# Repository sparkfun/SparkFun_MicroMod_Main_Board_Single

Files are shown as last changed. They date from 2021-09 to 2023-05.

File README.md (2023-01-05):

SparkFun MicroMod Main Board - Single
========================================

SparkFun MicroMod Main Board - Single (https://www.sparkfun.com/products/20748)

[*SparkFun MicroMod Main Board - Single (DEV-20748)*](https://www.sparkfun.com/products/20748)

The MicroMod Main Board - Single is a specialized carrier board that allows you to interface a MicroMod Processor Board with a single MicroMod Function Board. With the M.2 MicroMod connector, connecting your Processor and Function Boards is a breeze. Simply match up the key on your board's beveled edge connector to the key on the M.2 connector and secure the boards with screws.

The Single Main Board includes one USB-C connector for power and programming the Processor Board. A jumper is available on the back of the board to isolate the USB C's shield pin. Two buttons for reset and boot are also populated on the board. Processor Board pins are also broken out as 2x5 SWD pins. Also, included on the board is a 2A resettable fuse and 3.3V/1A voltage regulator. A second 3.3V/500mA voltage regulator is included on the board to power your Qwiic-enabled devices. We've even added convenient PTH jumpers for advanced users looking to bypass the fuse and measure the current consumption on the 5V and 3.3V lines for low-power testing. For those that need to go remote with their application, the board includes a 2-pin JST connector and a single-cell LiPo MCP73831 charge IC (set to a charge rate of 500mA).

Four status LEDs are available for power and charging. These can also be disabled through jumpers. There is a microSD card socket so you can also plug in a microSD card for data logging. The microSD socket can be disabled through the I/O pins. Finally, two Qwiic connectors are populated on the board with built-in pull-up resistors to easily add Qwiic-enabled I<sup>2</sup>C devices to your projects!

Repository Contents
-------------------

* **/Firmware** - Arduino example code from the tutorial
* **/Hardware** - Eagle design files (.brd, .sch)
* **/Production** - Production panel files (.brd)

Documentation
--------------

* **[Hookup Guide V2](https://learn.sparkfun.com/tutorials/2683)** - Basic hookup guide

Product Versions
----------------
* [DEV-20748](https://www.sparkfun.com/products/20748) - v2.1
* [DEV-18632](https://www.sparkfun.com/products/18575)- Initial release, v1.1

Version History
---------------
* v2.1
* v1.1 - Initial Release

License Information
-------------------

This product is _**open source**_! 

Please review the LICENSE.md file for license information. 

If you have any questions or concerns on licensing, please contact technical support on our [SparkFun forums](https://forum.sparkfun.com/viewforum.php?f=152).

Distributed as-is; no warranty is given.

- Your friends at SparkFun.

_<COLLABORATION CREDIT>_

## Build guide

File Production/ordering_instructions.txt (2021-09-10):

panel size, 187x173mm
PCB thickness, 1.6mm
number of layers, 2
soldermask color, Red
silkscreen color, White
oz copper, 1oz
finish, HASL lead free
stencils, top
pcs per panel, 4
min trace width, 0.1778mm / 0.0070in
min drill size, 0.3048mm / 0.0120in

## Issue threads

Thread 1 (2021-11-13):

Hardware revision request: Improved power efficiency

adamgarbo, 2021-11-13:
Hi @edspark,

I'm a big fan of MicroMod products and use them extensively in my [research](https://github.com/adamgarbo/Cryologger_Glacier_Velocity_Measurement_System).

Unfortunately, one of the major drawbacks with many of the MicroMod products has been poor power efficiency (e.g., https://github.com/sparkfun/MicroMod_Data_Logging_Carrier/issues/3, https://github.com/sparkfun/MicroMod_Artemis_Processor/issues/5)

The new Main Board are exciting products. However, it would have really been nice if some of the design improvements identified in previous MicroMod products were addressed in these new designs. For example: adding a jumper pad added to the voltage divider (i.e., https://github.com/sparkfun/MicroMod_Data_Logging_Carrier/issues/1), or adding a P-MOSFET or extra regulator to control power to the microSD card.

Low-power data logging is an extremely desirable feature for end-users. While I don't anticipate a hardware revision of the Main Boards, my hope is that low-power operation can be given more consideration in future MicroMod designs.

Cheers,
Adam

edspark, 2021-11-15:
These are both excellent suggestions. I've added them to my notes for future revisions, thank you @adamgarbo.

Closed 2021-11-15.

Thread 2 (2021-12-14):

breakout 3.3V_EN

pacogomez, 2021-12-14:
Hi @edspark,
I would like to control the voltage regulator with an on/off switch and controller circuit, which will be connected to the pin on the processor (3.3V_EN). My suggestion is:
- add a breakout pin for EN signal (voltage regulator enable pin)
- add a breakout pin for 3.3V_EN (processor board pin)
In other words, convert the "Voltage Regulator Enable/VE" jumper to a two pin breakout.
Thanks.

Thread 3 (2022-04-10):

MicroMod MainBoard Double which causes the processor board to become unresponsive

paulvha, 2022-04-10:
There is a concerning issue with the MicroMod MainBoard Double which causes the processor board to become unresponsive.
It has already **killed my Micromod SAMD51 and Micromod rnf52840.** I am not alone in looking at post https://forum.sparkfun.com/viewtopic.php?f=181&t=57369. Similar problem.

Both these processor boards have been working without a problem. I had them installed in MM Data logger board AND on the MM Mainboard Double, but without the function board! I have done a number of different projects over the past weeks, and uploaded many sketches, no problems!

All I had done is :
No battery attached.
Add a function board (mine was the ESP32 WIFI) in SLOT zero.
No function board is SLOT ONE
I had changed the default power jumper setting from right (default) to left.
Upload a sketch

and **the processor board could not be reached anymore**. Similar to what happened with the other person on the post.

On my Ubuntu I do not get /dev/ttyUSB0 and /dev/ttyACM0 anymore and I have tried every trick I can think off, but nothing helps to recover:

- Remove the function board and re-power. Both the power LEDs come on, but **all MM nRF52840 does is the blue onboard led 4 x slow blink, 4 x fast blink.**
- press reset
- press and hold reset during power-on.
- press boot
- press and hold boot during power-on.
- press boot and Reset
- press and hold boot and reset during power-on.
- Used the MM data logger board instead of mainboard
- Used the MM  ATP (DEV-16885)
- Reboot the Ubuntu system
- Connect to a windows system USB

Nothing.. processor boards are dead as they can be, only the nRF52840 led blinking 4x slow, 4 x fast.

I suspected impact from the Power Jumper setting option.

On the ESP32 WIFI function board, the PWR-enablement pin is pulled HIGH with resistor R12 near the LDO. So the power is always ON, unless it is switched OFF in a sketch. The PWR-EN0 is HIGH from the moment the power is applied.

On the MM MainBoard double, the PWR_EN0 is connected to MM processor board connector SDIO-data2 (68).

With the power Jumper setting to the left, the PWR_EN0 is now also connected to G5-Jumper on the MM-processor board, which is now HIGH as well. (coming from PWR_EN0)

On the MM nRF52840 processor board, the SDIO-data2 is not only connected to the nRF52840 BUT ALSO connected to the on-board flash.
When now uploading a sketch... what does that 'HIGH' impact when trying to load the flash memory?

BUT....

On the MM SAMD51 processor board, the SDIO-data2 is not used and while G5-jumper is HIGH, it is just a normal GPIO. But I can't think of a reason why that would damage the board. The same applies to the MM STM32 that was used by the other person.

Other thoughts :

- One could think it is because the USB and CAN connections are also going to function zero connector, but the ESP32 Wifi function board does not use these.

- If it is not the power jumper, might it be that too much current is taken by both the processor board and function board during flashing the sketch?

- I am not sure whether I had the MicroSD still in the reader for the MM mainboard double together with the function board. I had been using it before (and left it in during uploading an updated sketch without problems. Maybe that took extra power ??

I still have an MM Artemis and MM ESP32.. but killing 2 boards is enough. I can and make errors, but given that another user (mentioned in the earlier link) had the same issue, given that it is SOO easy to happen.. I **think Sparkfun should look at this.**

regards,
Paul

p.s.
Brave, or stupid, as I am. I removed the function board, installed the MM Artemis on the MM mainboard double, and uploaded the example sketch from the hookup guide. Powered down, added the ESP32 WIFI function board, powered up and it worked. But to be sure.. **I will not upload a sketch with the function board inserted...**

paulvha, 2022-04-14:
I have updated with an observation about the charge led on the Sparkfun Forum.
regards,
Paul

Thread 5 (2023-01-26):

CAN-RX and CAN-TX Labels are reversed on MICROMOD_FUNCTION symbol

NPoole, 2023-01-26:
As it's currently labeled, this board appears to connect the processor board's CAN-RX to the function board's CAN-TX and vise versa, but this is incorrect. I've updated the library symbol in the Eagle library to fix the labels without changing the wiring. Next time this board gets revved, replace MICROMOD_FUNCTION_MAIN with the new version and replace pins "by coordinates" (not "by names") in order to ensure the schematic is fixed.

To reiterate, the correct connection scheme is TX-TX and RX-RX

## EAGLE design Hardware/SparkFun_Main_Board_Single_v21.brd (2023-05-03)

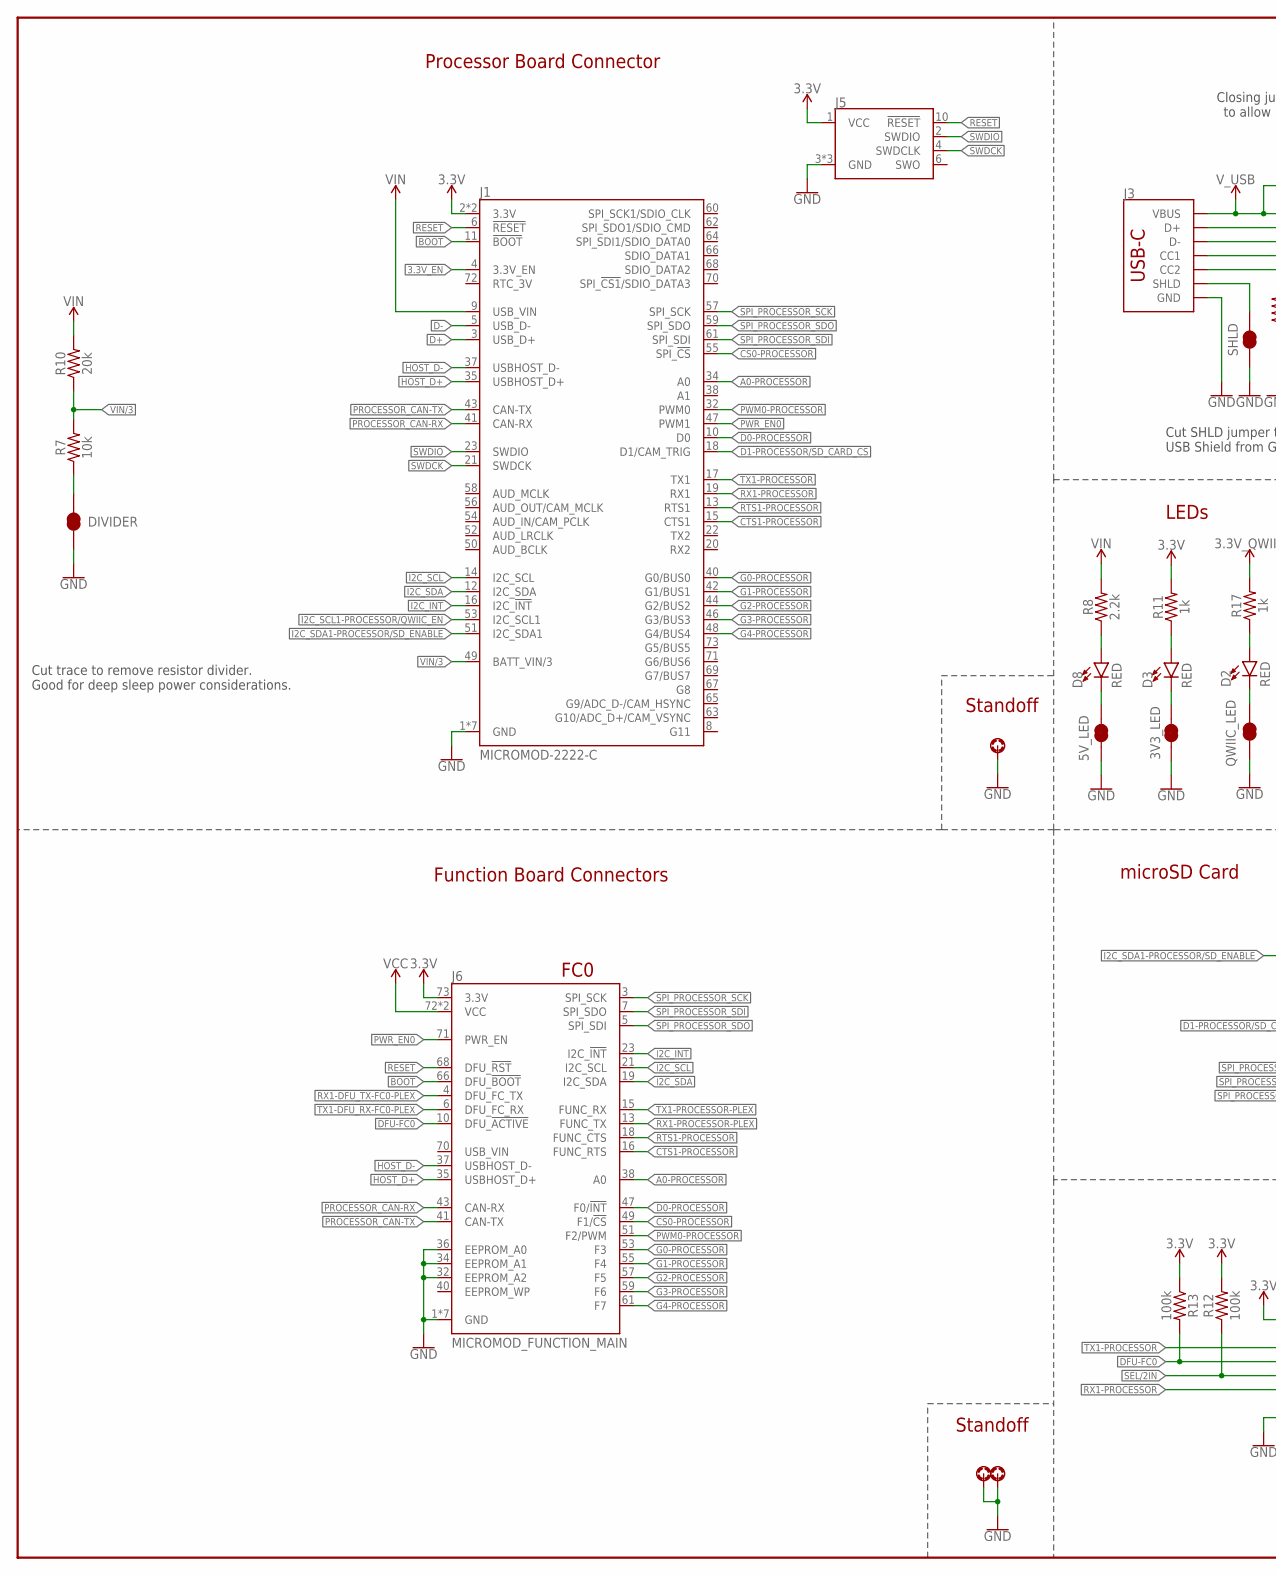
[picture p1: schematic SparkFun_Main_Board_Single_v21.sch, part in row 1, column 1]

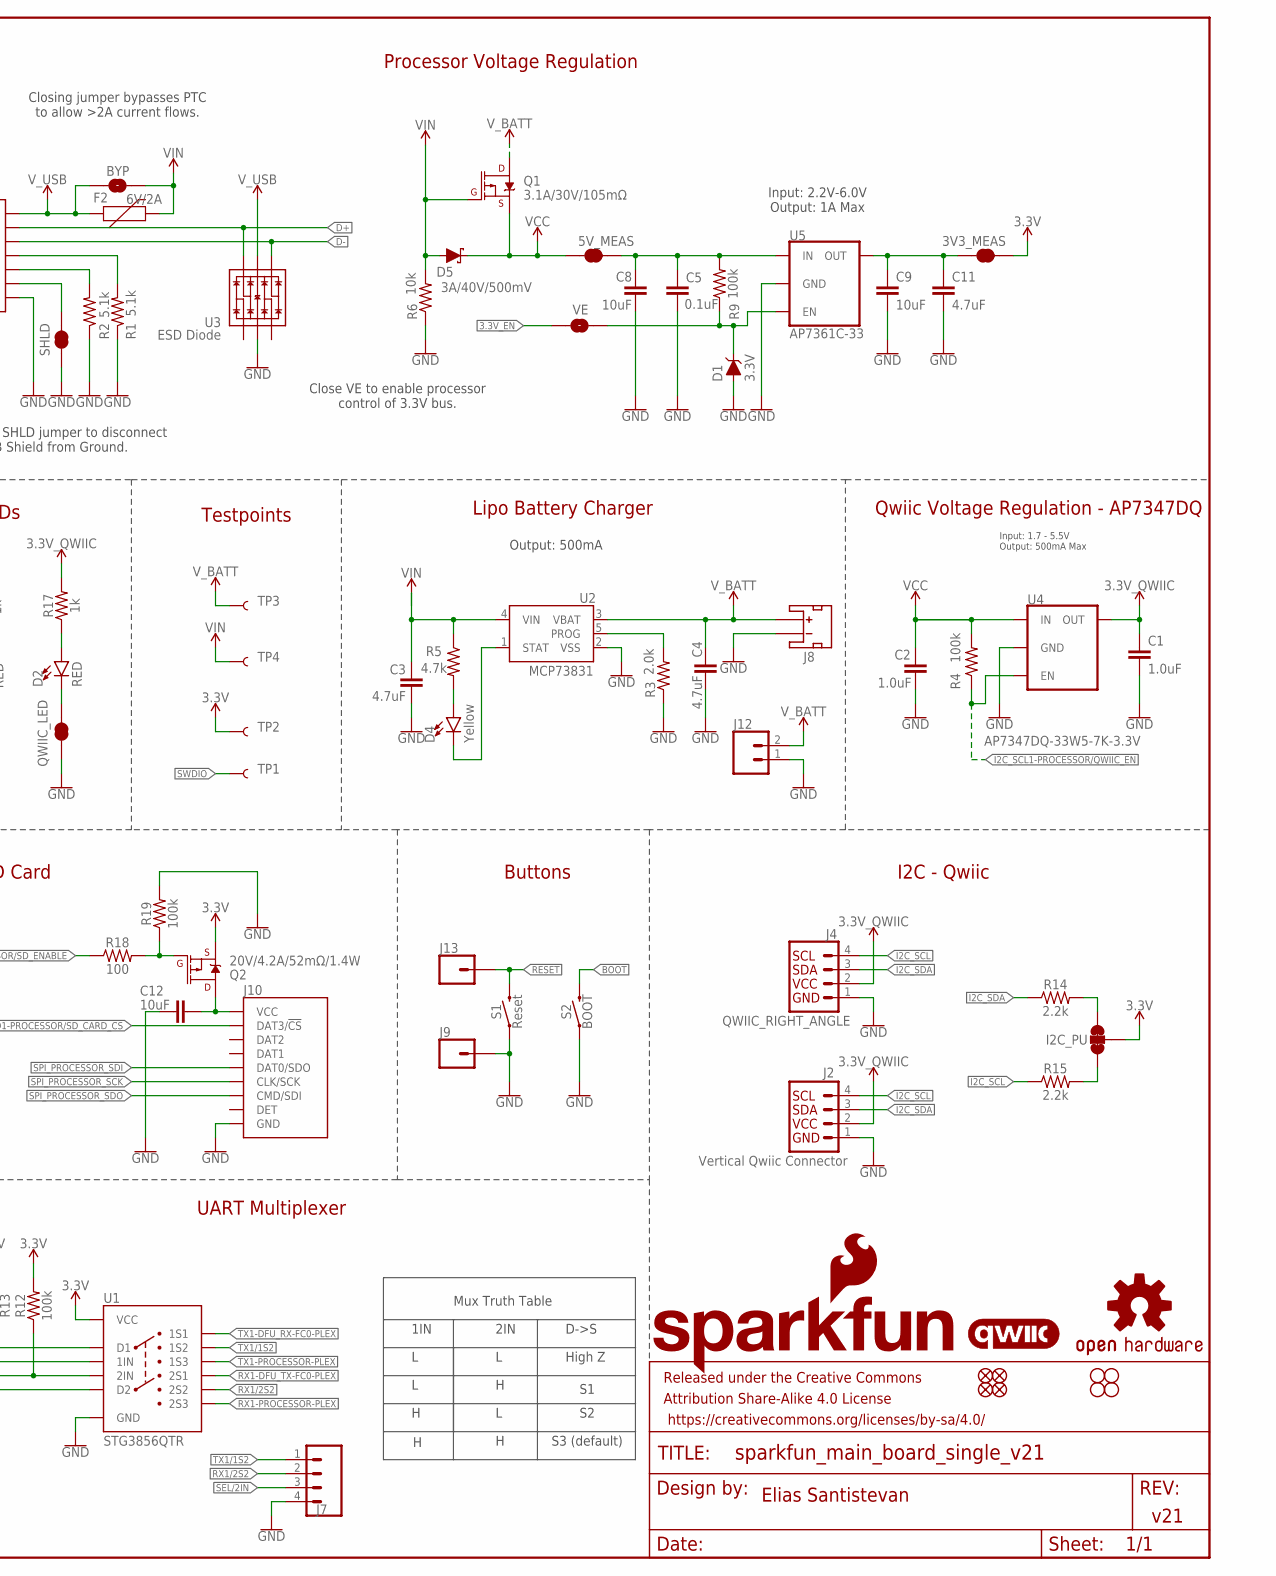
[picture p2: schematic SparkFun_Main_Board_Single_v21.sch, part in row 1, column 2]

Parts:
3V3_LED, 5V_LED: JUMPER-SMT_2_NC_TRACE_SILK; SMT-JUMPER_2_NC_TRACE_SILK
3V3_MEAS, 5V_MEAS: JUMPER-COMBO_2_NC_TRACE; COMBO-JUMPER_2_NC_TRACE
BYP: JUMPER-SMT_2_NO_SILK; SMT-JUMPER_2_NO_SILK
C1, C2: 1.0uF; 0603
C3, C4, C11: 4.7uF; 0603
C5: 0.1uF; 0603
C8: 10uF; 0805
C9, C12: 10uF; 0603
D1: 3.3V; SOD-323
D2, D3, D8: RED; LED-0603
D4: Yellow; LED-0603
D5: 3A/40V/500mV; SMA-DIODE
DIVIDER: JUMPER-SMT_2_NC_TRACE_SILK; SMT-JUMPER_2_NC_TRACE_SILK
F2: 6V/2A; 1210
FD1, FD2, FD3, FD4: FIDUCIAL1X2; FIDUCIAL-1X2
FRAME1: FRAME-LEDGER; CREATIVE_COMMONS
H2, H4, H8: STAND-OFF-REFLOW-M2.5_2.5MM_TALL; STAND-OFF-REFLOW-M2.5
H14, H15, H16, H17: STAND-OFFTIGHT; STAND-OFF-TIGHT
I2C_PU: JUMPER-SMT_3_2-NC_TRACE_SILK; SMT-JUMPER_3_2-NC_TRACE_SILK
J1: MICROMOD-2222-C; M.2-CONNECTOR-E
J2: Vertical Qwiic Connector; JST04_1MM_VERT
J3: USB_C_2-LAYER_PADS; USB-C-16P-2LAYER-PADS
J4: QWIIC_RIGHT_ANGLE; JST04_1MM_RA
J5: CORTEX_JTAG_DEBUG_MINIMUM_PTH; 2X5-PTH-1.27MM
J6: MICROMOD_FUNCTION_MAIN; M.2-CONNECTOR-E-FUNCTION-STANDARD
J7: CONN_041X04_NO_SILK; 1X04_NO_SILK
J8: JST_2MM_MALE; JST-2-SMD
J9, J13: CONN_01PTH_NO_SILK_YES_STOP; 1X01_NO_SILK
J10: MICRO-SD-PUSH-PUSH-EXT-PIN; MICROSD-EXTERNALPIN
J12: CONN_021X02_NO_SILK; 1X02_NO_SILK
LOGO1: QWIIC_LOGO_8MM; QWIIC_8MM
LOGO2: SFE_LOGO_NAME_FLAME.3_INCH; SFE_LOGO_NAME_FLAME_.3
LOGO3: OSHW-LOGOL; OSHW-LOGO-L
Q1: 3.1A/30V/105mΩ; SOT23-3
Q2: 20V/4.2A/52mΩ/1.4W; SOT23-3
QWIIC_LED: JUMPER-SMT_2_NC_TRACE_SILK; SMT-JUMPER_2_NC_TRACE_SILK
R1, R2: 5.1k; 0603
R3: 2.0k; 0603
R4, R9, R12, R13, R19: 100k; 0603
R5: 4.7k; 0603
R6, R7: 10k; 0603
R8, R14, R15: 2.2k; 0603
R10: 20k; 0603
R11, R17: 1k; 0603
R18: 100; 0603
S1: Reset; TACTILE_SWITCH_SMD_5.2MM
S2: BOOT; TACTILE_SWITCH_SMD_5.2MM
SHLD: JUMPER-SMT_2_NC_TRACE_SILK; SMT-JUMPER_2_NC_TRACE_SILK
TP1, TP2, TP3, TP4: TEST-POINT3X5; PAD.03X.05
U1: STG3856QTR; STG3856
U2: MCP73831; SOT23-5
U3: ESD Diode; SOT-23-6
U4: AP7347DQ-33W5-7K-3.3V; SOT25
U5: AP7361C-33; UDFN-8
VE: JUMPER-SMT_2_NO_SILK; SMT-JUMPER_2_NO_SILK

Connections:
3.3V: 3V3_MEAS.2, 3V3_MEAS.4 (2), I2C_PU.2, J1.2 (3.3V), J1.74 (3.3V), J5.1 (VCC), J6.73 (3.3V), Q2.2 (S), R11.2, R12.2, R13.1, TP2.1, U1.P11 (VCC)
3.3V_EN: J1.4 (3.3V_EN), VE.1
3.3V_EN_VE: D1.C, R9.1, U5.5 (EN), VE.2
3.3V_QWIIC: C1.1, J2.2, J4.2, R17.2, U4.5 (OUT)
3V3_MEAS: 3V3_MEAS.1, 3V3_MEAS.3 (1), C9.1, C11.1, U5.1 (OUT)
!BOOT!: J1.11 (!BOOT!), J6.66 (DFU_!BOOT!), S2.3 (2), S2.4 (2)
!CS0!-PROCESSOR: J1.55 (SPI_!CS!), J6.49 (F1/!CS!)
!DFU-FC0!: J6.10 (DFU_!ACTIVE!), R13.2, U1.P12 (1IN)
!RESET!: J1.6 (!RESET!), J5.10 (!RESET), J6.68 (DFU_!RST!), J13.1, S1.3 (2), S1.4 (2)
!SEL!/2IN: J7.3, R12.1, U1.P10 (2IN)
A0-PROCESSOR: J1.34 (A0), J6.38 (A0)
CTS1-PROCESSOR: J1.15 (CTS1), J6.16 (FUNC_RTS)
D0-PROCESSOR: J1.10 (D0), J6.47 (F0/!INT!)
D1-PROCESSOR/SD_CARD_!CS!: J1.18 (D1/CAM_TRIG), J10.2 (DAT3/!CS!)
D+: J1.3 (USB_D+), J3.A6 (D+), J3.B6 (D+), U3.6 (IO4)
D-: J1.5 (USB_D-), J3.A7 (D-), J3.B7 (D-), U3.4 (IO3)
G0-PROCESSOR: J1.40 (G0/BUS0), J6.53 (F3)
G1-PROCESSOR: J1.42 (G1/BUS1), J6.55 (F4)
G2-PROCESSOR: J1.44 (G2/BUS2), J6.57 (F5)
G3-PROCESSOR: J1.46 (G3/BUS3), J6.59 (F6)
G4-PROCESSOR: J1.48 (G4/BUS4), J6.61 (F7)
GND: 3V3_LED.1, 5V_LED.1, C1.2, C2.2, C3.2, C4.2, C5.2, C8.2, C9.2, C11.2, C12.2, D1.A, DIVIDER.1, H2.1, H4.1, H8.1, J1.1 (GND), J1.7 (GND), J1.33 (GND), J1.36 (GND), J1.39 (GND), J1.45 (GND), J1.75 (GND), J2.1, J3.GND, J3.GND2 (GND), J4.1, J5.3 (GND), J5.5 (GND), J5.9 (GND), J6.1 (GND), J6.2 (GND), J6.8 (GND), J6.32 (EEPROM_A2), J6.33 (GND), J6.34 (EEPROM_A1), J6.36 (EEPROM_A0), J6.39 (GND), J6.45 (GND), J6.75 (GND), J7.4, J8.1 (-), J9.1, J10.6 (GND), J10.10 (GND), J10.11 (GND), J10.12 (GND), J10.13 (GND), J12.1, QWIIC_LED.1, R1.1, R2.1, R3.1, R6.1, R19.2, S1.1, S1.2 (1), S2.1, S2.2 (1), SHLD.1, U1.P5 (GND), U2.2 (VSS), U3.2 (VSS), U4.2 (GND), U5.4 (GND), U5.EP (GND)
HOST_D+: J1.35 (USBHOST_D+), J6.35 (USBHOST_D+)
HOST_D-: J1.37 (USBHOST_D-), J6.37 (USBHOST_D-)
I2C_!INT!: J1.16 (I2C_!INT!), J6.23 (I2C_!INT!)
I2C_SCL: J1.14 (I2C_SCL), J2.4, J4.4, J6.21 (I2C_SCL), R15.1
I2C_SCL1-PROCESSOR/QWIIC_EN: J1.53 (I2C_SCL1), R4.1, U4.3 (EN)
I2C_SDA: J1.12 (I2C_SDA), J2.3, J4.3, J6.19 (I2C_SDA), R14.1
I2C_SDA1-PROCESSOR/!SD_ENABLE!: J1.51 (I2C_SDA1), R18.1
unnamed: 5V_LED.2, D8.C
unnamed: D3.A, R11.1
unnamed: J3.B5 (CC2), R2.2
unnamed: J3.A5 (CC1), R1.2
unnamed: R3.2, U2.5 (PROG)
unnamed: DIVIDER.2, R7.1
unnamed: D4.C, U2.1 (STAT)
unnamed: D4.A, R5.2
unnamed: 3V3_LED.2, D3.C
unnamed: I2C_PU.3, R14.2
unnamed: D8.A, R8.1
unnamed: I2C_PU.1, R15.2
unnamed: D2.A, R17.1
unnamed: D2.C, QWIIC_LED.2
unnamed: C12.1, J10.4 (VCC), Q2.3 (D)
unnamed: Q2.1 (G), R18.2, R19.1
PROCESSOR_CAN-RX: J1.41 (CAN-RX), J6.43 (CAN-RX)
PROCESSOR_CAN-TX: J1.43 (CAN-TX), J6.41 (CAN-TX)
PWM0-PROCESSOR: J1.32 (PWM0), J6.51 (F2/PWM)
PWR_EN0: J1.47 (PWM1), J6.71 (PWR_EN)
RTS1-PROCESSOR: J1.13 (RTS1), J6.18 (FUNC_CTS)
RX1-DFU_TX-FC0-PLEX: J6.4 (DFU_FC_TX), U1.P9 (2S1)
RX1-PROCESSOR: J1.19 (RX1), U1.P6 (D2)
RX1-PROCESSOR-PLEX: J6.13 (FUNC_TX), U1.P7 (2S3)
RX1/2S2: J7.2, U1.P8 (2S2)
SHLD: J3.SHLD1 (SHLD), J3.SHLD2 (SHLD), J3.SHLD3 (SHLD), J3.SHLD4 (SHLD), SHLD.2
SPI_PROCESSOR_SCK: J1.57 (SPI_SCK), J6.3 (SPI_SCK), J10.5 (CLK/SCK)
SPI_PROCESSOR_SDI: J1.61 (SPI_SDI), J6.7 (SPI_SDO), J10.7 (DAT0/SDO)
SPI_PROCESSOR_SDO: J1.59 (SPI_SDO), J6.5 (SPI_SDI), J10.3 (CMD/SDI)
SWDCK: J1.21 (SWDCK), J5.4 (SWDCLK)
SWDIO: J1.23 (SWDIO), J5.2 (SWDIO), TP1.1
TX1-DFU_RX-FC0-PLEX: J6.6 (DFU_FC_RX), U1.P1 (1S1)
TX1-PROCESSOR: J1.17 (TX1), U1.P4 (D1)
TX1-PROCESSOR-PLEX: J6.15 (FUNC_RX), U1.P3 (1S3)
TX1/1S2: J7.1, U1.P2 (1S2)
VCC: 5V_MEAS.1, 5V_MEAS.3 (1), C2.1, D5.C, J6.72 (VCC), J6.74 (VCC), Q1.2 (S), R4.2, U4.1 (IN)
VCC_MEAS: 5V_MEAS.2, 5V_MEAS.4 (2), C5.1, C8.1, R9.2, U5.8 (IN)
VIN: BYP.2, C3.1, D5.A, F2.2, J1.9 (USB_VIN), Q1.1 (G), R5.1, R6.2, R8.2, R10.2, TP4.1, U2.4 (VIN)
VIN/3: J1.49 (BATT_VIN/3), R7.2, R10.1
V_BATT: C4.1, J8.2 (+), J12.2, Q1.3 (D), TP3.1, U2.3 (VBAT)
V_USB: BYP.1, F2.1, J3.VBUS1 (VBUS), J3.VBUS2 (VBUS), U3.5 (VCC)

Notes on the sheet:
Function Board Connectors
Processor Board Connector
v21
I2C - Qwiic
FC0
Lipo Battery Charger
Testpoints
Processor Voltage Regulation
Closing jumper bypasses PTC to allow >2A current flows.
Input: 2.2V-6.0V Output: 1A Max
Close VE to enable processor control of 3.3V bus.
LEDs
Buttons
Elias Santistevan
Standoff
Mux Truth Table
1IN
2IN
D->S
High Z
S3 (default)
UART Multiplexer
Qwiic Voltage Regulation - AP7347DQ
Input: 1.7 - 5.5V Output: 500mA Max
Output: 500mA
Cut SHLD jumper to disconnect USB Shield from Ground.
microSD Card
Cut trace to remove resistor divider. Good for deep sleep power considerations.

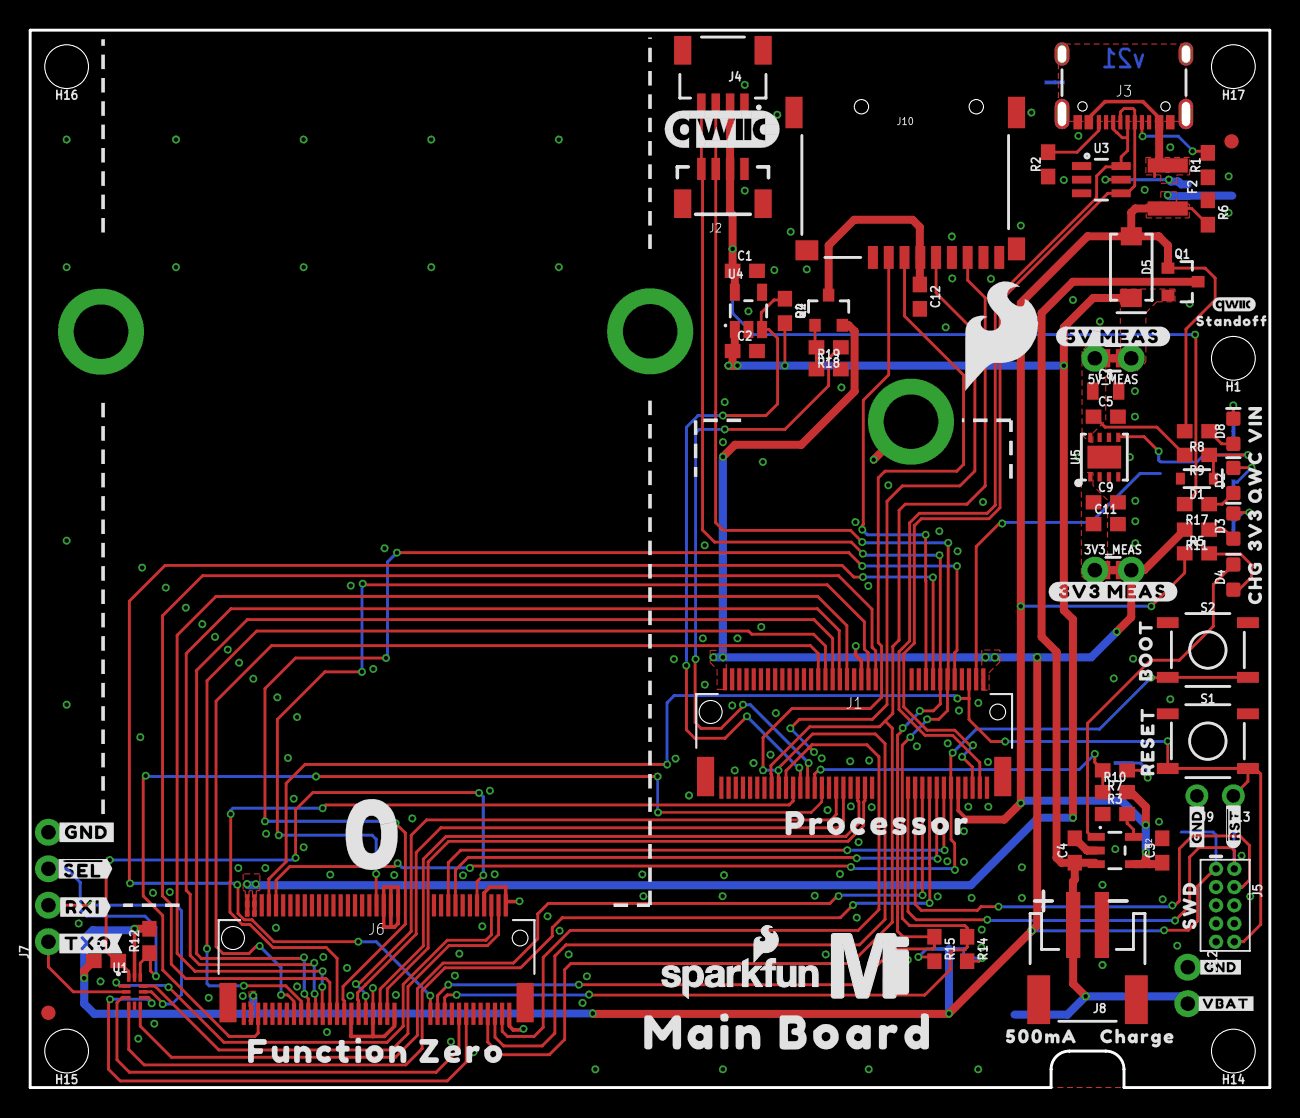
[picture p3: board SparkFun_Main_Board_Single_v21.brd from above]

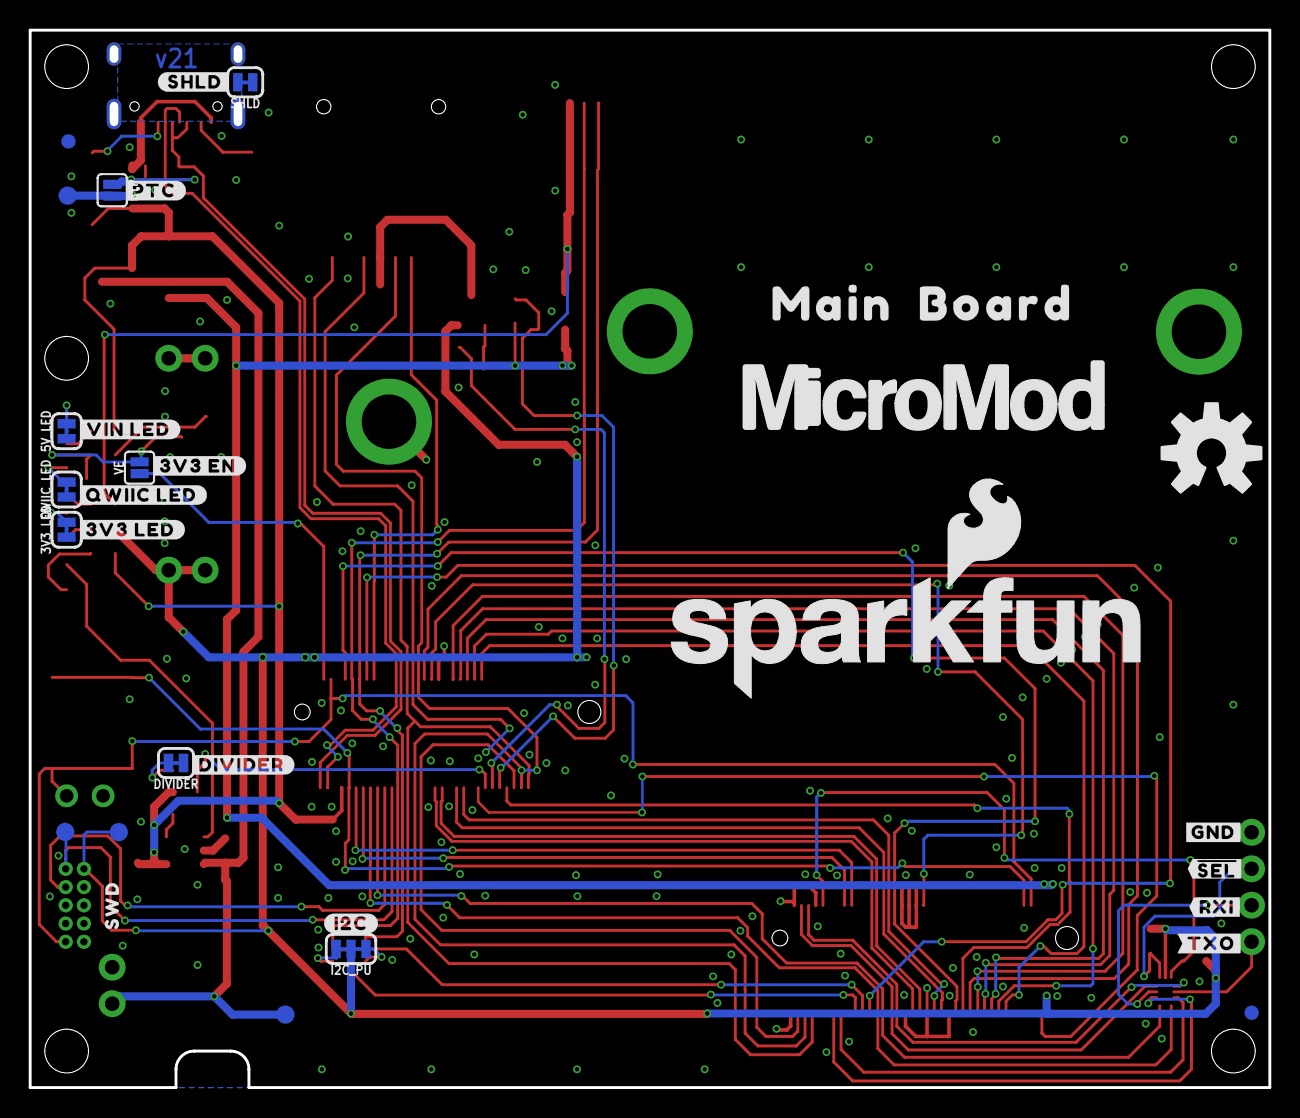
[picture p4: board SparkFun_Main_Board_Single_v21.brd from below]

Board: 2 copper layers, 86.4 x 73.7 mm, 130 parts (32 on the bottom side), 70 nets.

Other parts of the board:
FRAME2: FRAME-LEDGERNO_FOOTPRINT; DUMMY
H1: STAND-OFFTIGHT; STAND-OFF-TIGHT
U$1: #TXO#7
U$2: #RXI#6
U$3: #PTC#15
U$4: 3V332533
U$5: VIN32532
U$6: CHG32531
U$7: #SHLD#501
U$8: BOOT32541
U$9: RESET32540
U$10: PROCESSOR525
U$11: FUNCTION_ZERO520
U$12: ##SEL##5
U$13: MAIN523
U$14: MICROMOD_MI_LOGO_1
U$15: 0523
U$16, U$29: #GND#3
U$17: MICROMOD_LOGO_1
U$18: BOARD524
U$19: ##SEL##3
U$20: #RXI#4
U$21: MAIN_BOARD5523
U$22: QWIIC_3MM
U$23: STANDOFF501
U$24: SFE_LOGO_FLAME_.3
U$25, U$32: SWD6522
U$26: #3V3_MEAS#6522
U$27: CHARGE501
U$28: #TXO#5
U$30: #I2C#501
U$31: #5V_MEAS#6522
U$33: 500MA6520
U$34: SFE_LOGO_NAME_FLAME_.1
U$35: QWC4
U$36, U$37: #GND#10
U$38: ##RST##8
U$39: #VBAT#9
U$49: #3V3_EN#23
U$50: #3V3_LED#22
U$51: #QWIIC_LED#22
U$52: #DIVIDER#23
U$53: #VIN_LED#24

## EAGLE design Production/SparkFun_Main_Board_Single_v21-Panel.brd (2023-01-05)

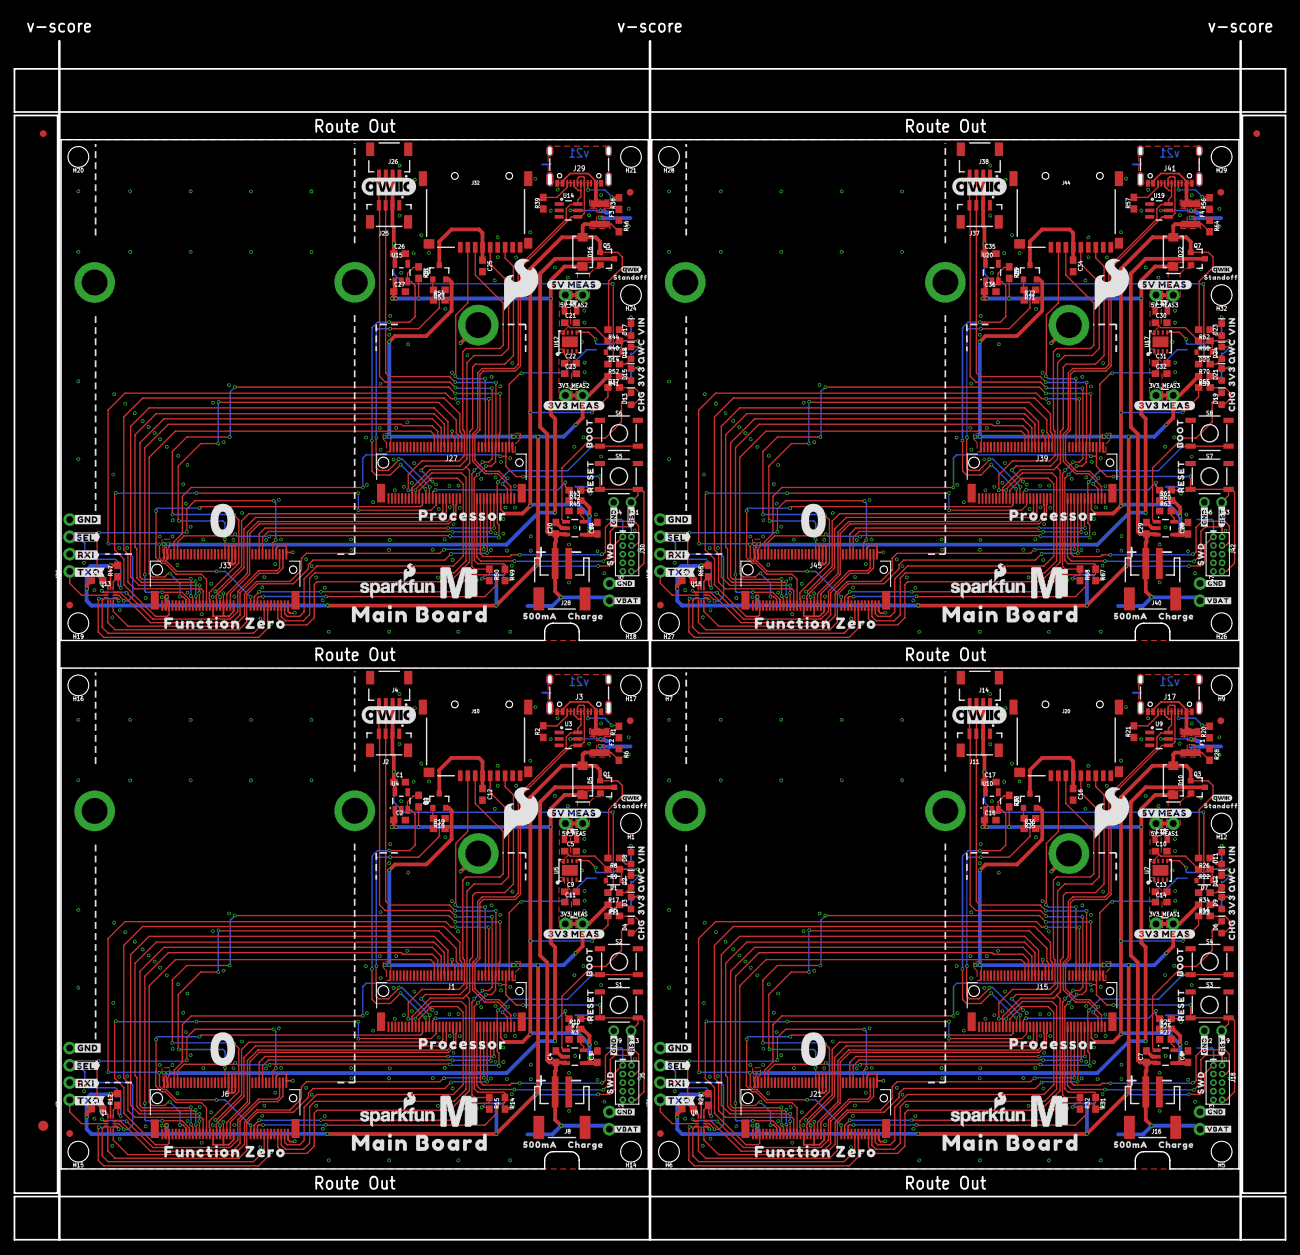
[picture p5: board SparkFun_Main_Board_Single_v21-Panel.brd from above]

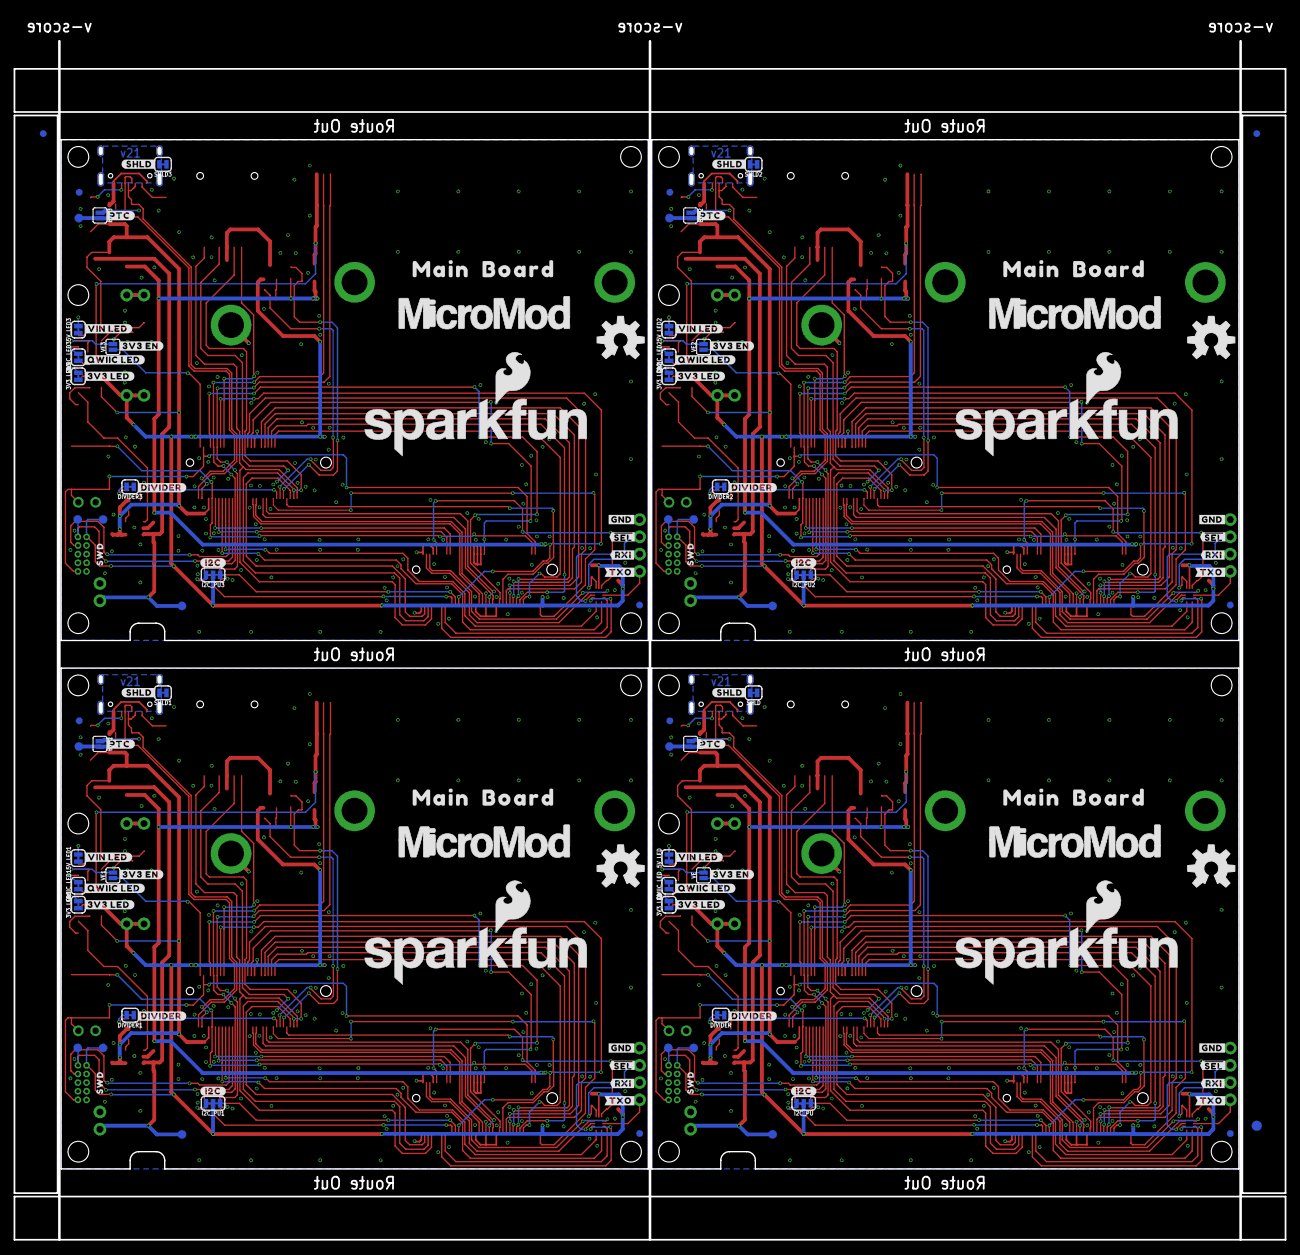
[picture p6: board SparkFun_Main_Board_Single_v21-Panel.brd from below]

Board: 2 copper layers, 186.9 x 176.3 mm, 518 parts (131 on the bottom side), 280 nets.

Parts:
3V3_LED, 3V3_LED1, 3V3_LED2, 3V3_LED3, 5V_LED, 5V_LED1, 5V_LED2, 5V_LED3: JUMPER-SMT_2_NC_TRACE_SILK; SMT-JUMPER_2_NC_TRACE_SILK
3V3_MEAS, 3V3_MEAS1, 3V3_MEAS2, 3V3_MEAS3, 5V_MEAS, 5V_MEAS1, 5V_MEAS2, 5V_MEAS3: JUMPER-COMBO_2_NC_TRACE; COMBO-JUMPER_2_NC_TRACE
BYP, BYP1, BYP2, BYP3: JUMPER-SMT_2_NO_SILK; SMT-JUMPER_2_NO_SILK
C1, C2, C17, C18, C26, C27, C35, C36: 1.0uF; 0603
C3, C4, C6, C7, C11, C14, C19, C20, C23, C28, C29, C32: 4.7uF; 0603
C5, C10, C21, C30: 0.1uF; 0603
C8, C15, C24, C33: 10uF; 0805
C9, C12, C13, C16, C22, C25, C31, C34: 10uF; 0603
D1, D7, D14, D20: 3.3V; SOD-323
D2, D3, D8, D9, D11, D12, D15, D17, D18, D21, D23, D24: RED; LED-0603
D4, D6, D13, D19: Yellow; LED-0603
D5, D10, D16, D22: 3A/40V/500mV; SMA-DIODE
DIVIDER, DIVIDER1, DIVIDER2, DIVIDER3: JUMPER-SMT_2_NC_TRACE_SILK; SMT-JUMPER_2_NC_TRACE_SILK
E$1, E$2, E$3, E$4: FIDUCIAL-1X2
E$5, E$6: FIDUCIAL-1.5X3
F1, F2, F3, F4: 6V/2A; 1210
FD1, FD2, FD3, FD4, FD5, FD6, FD7, FD8, FD9, FD10, FD11, FD12, FD13, FD14, FD15, FD16: FIDUCIAL1X2; FIDUCIAL-1X2
H1, H5, H6, H7, H9, H12, H14, H15, H16, H17, H18, H19, H20, H21, H24, H26, H27, H28, H29, H32: STAND-OFFTIGHT; STAND-OFF-TIGHT
H2, H3, H4, H8, H10, H11, H13, H22, H23, H25, H30, H31: STAND-OFF-REFLOW-M2.5_2.5MM_TALL; STAND-OFF-REFLOW-M2.5
I2C_PU, I2C_PU1, I2C_PU2, I2C_PU3: JUMPER-SMT_3_2-NC_TRACE_SILK; SMT-JUMPER_3_2-NC_TRACE_SILK
J1, J15, J27, J39: MICROMOD-2222-C; M.2-CONNECTOR-E
J2, J11, J25, J37: Vertical Qwiic Connector; JST04_1MM_VERT
J3, J17, J29, J41: USB-C-16P-2LAYER-PADS
J4, J14, J26, J38: QWIIC_RIGHT_ANGLE; JST04_1MM_RA
J5, J18, J30, J42: CORTEX_JTAG_DEBUG_MINIMUM_PTH; 2X5-PTH-1.27MM
J6, J21, J33, J45: MICROMOD_FUNCTION_MAIN; M.2-CONNECTOR-E-FUNCTION-STANDARD
J7, J24, J36, J48: 1X04_NO_SILK
J8, J16, J28, J40: JST-2-SMD
J9, J13, J19, J22, J31, J34, J43, J46: 1X01_NO_SILK
J10, J20, J32, J44: MICRO-SD-PUSH-PUSH-EXT-PIN; MICROSD-EXTERNALPIN
J12, J23, J35, J47: 1X02_NO_SILK
LOGO1, LOGO4, LOGO7, LOGO10: QWIIC_LOGO_8MM; QWIIC_8MM
LOGO2, LOGO5, LOGO8, LOGO11: SFE_LOGO_NAME_FLAME.3_INCH; SFE_LOGO_NAME_FLAME_.3
LOGO3, LOGO6, LOGO9, LOGO12: OSHW-LOGOL; OSHW-LOGO-L
Q1, Q3, Q5, Q7: 3.1A/30V/105mΩ; SOT23-3
Q2, Q4, Q6, Q8: 20V/4.2A/52mΩ/1.4W; SOT23-3
QWIIC_LED, QWIIC_LED1, QWIIC_LED2, QWIIC_LED3: JUMPER-SMT_2_NC_TRACE_SILK; SMT-JUMPER_2_NC_TRACE_SILK
R1, R2, R20, R21, R38, R39, R56, R57: 5.1k; 0603
R3, R27, R45, R63: 2.0k; 0603
R4, R9, R12, R13, R19, R22, R29, R30, R33, R36, R40, R47, R48, R51, R54, R58, R65, R66, R69, R72: 100k; 0603
R5, R16, R37, R55: 4.7k; 0603
R6, R7, R24, R28, R42, R46, R60, R64: 10k; 0603
R8, R14, R15, R26, R31, R32, R44, R49, R50, R62, R67, R68: 2.2k; 0603
R10, R25, R43, R61: 20k; 0603
R11, R17, R23, R34, R41, R52, R59, R70: 1k; 0603
R18, R35, R53, R71: 100; 0603
S1, S3, S5, S7: Reset; TACTILE_SWITCH_SMD_5.2MM
S2, S4, S6, S8: BOOT; TACTILE_SWITCH_SMD_5.2MM
SHLD, SHLD1, SHLD2, SHLD3: JUMPER-SMT_2_NC_TRACE_SILK; SMT-JUMPER_2_NC_TRACE_SILK
TP1, TP2, TP3, TP4, TP5, TP6, TP7, TP8, TP9, TP10, TP11, TP12, TP13, TP14, TP15, TP16: TEST-POINT3X5; PAD.03X.05
U1, U8, U13, U18: STG3856QTR; STG3856
U2, U6, U11, U16: MCP73831; SOT23-5
U3, U9, U14, U19: ESD Diode; SOT-23-6
U4, U10, U15, U20: AP7347DQ-33W5-7K-3.3V; SOT25
U5, U7, U12, U17: AP7361C-33; UDFN-8
U$1, U$78, U$122, U$166: #TXO#7
U$2, U$79, U$123, U$167: #RXI#6
U$3, U$84, U$128, U$172: #PTC#15
U$4, U$40, U$89, U$133: 3V332533
U$5, U$41, U$90, U$134: VIN32532
U$6, U$42, U$91, U$135: CHG32531
U$7, U$62, U$106, U$150: #SHLD#501
U$8, U$43, U$92, U$136: BOOT32541
U$9, U$44, U$93, U$137: RESET32540
U$10, U$45, U$94, U$138: PROCESSOR525
U$11, U$46, U$95, U$139: FUNCTION_ZERO520
U$12, U$80, U$124, U$168: ##SEL##5
U$13, U$54, U$98, U$142: MAIN523
U$14, U$47, U$96, U$140: MICROMOD_MI_LOGO_1
U$15, U$48, U$97, U$141: 0523
U$16, U$29, U$73, U$74, U$117, U$118, U$161, U$162: #GND#3
U$17, U$57, U$101, U$145: MICROMOD_LOGO_1
U$18, U$55, U$99, U$143: BOARD524
U$19, U$81, U$125, U$169: ##SEL##3
U$20, U$82, U$126, U$170: #RXI#4
U$21, U$56, U$100, U$144: MAIN_BOARD5523
U$22, U$58, U$102, U$146: QWIIC_3MM
U$23, U$59, U$103, U$147: STANDOFF501
U$24, U$60, U$104, U$148: SFE_LOGO_FLAME_.3
U$25, U$32, U$66, U$75, U$110, U$119, U$154, U$163: SWD6522
U$26, U$63, U$107, U$151: #3V3_MEAS#6522
U$27, U$61, U$105, U$149: CHARGE501
U$28, U$83, U$127, U$171: #TXO#5
U$30, U$72, U$116, U$160: #I2C#501
U$31, U$64, U$108, U$152: #5V_MEAS#6522
U$33, U$65, U$109, U$153: 500MA6520
U$34, U$76, U$120, U$164: SFE_LOGO_NAME_FLAME_.1
U$35, U$77, U$121, U$165: QWC4
U$36, U$37, U$85, U$86, U$129, U$130, U$173, U$174: #GND#10
U$38, U$87, U$131, U$175: ##RST##8
U$39, U$88, U$132, U$176: #VBAT#9
U$49, U$67, U$111, U$155: #3V3_EN#23
U$50, U$68, U$112, U$156: #3V3_LED#22
U$51, U$69, U$113, U$157: #QWIIC_LED#22
U$52, U$70, U$114, U$158: #DIVIDER#23
U$53, U$71, U$115, U$159: #VIN_LED#24
VE, VE1, VE2, VE3: JUMPER-SMT_2_NO_SILK; SMT-JUMPER_2_NO_SILK

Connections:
3.3V: 3V3_MEAS.2, 3V3_MEAS.4, I2C_PU.2, J1.2, J1.74, J5.1, J6.73, Q2.2, R11.2, R12.2, R13.1, TP2.1, U1.P11
3.3V1: 3V3_MEAS1.2, 3V3_MEAS1.4, I2C_PU1.2, J15.2, J15.74, J18.1, J21.73, Q4.2, R23.2, R29.2, R30.1, TP5.1, U8.P11
3.3V2: 3V3_MEAS2.2, 3V3_MEAS2.4, I2C_PU2.2, J27.2, J27.74, J30.1, J33.73, Q6.2, R41.2, R47.2, R48.1, TP9.1, U13.P11
3.3V3: 3V3_MEAS3.2, 3V3_MEAS3.4, I2C_PU3.2, J39.2, J39.74, J42.1, J45.73, Q8.2, R59.2, R65.2, R66.1, TP13.1, U18.P11
3.3V_EN: J1.4, VE.1
3.3V_EN1: J15.4, VE1.1
3.3V_EN2: J27.4, VE2.1
3.3V_EN3: J39.4, VE3.1
3.3V_EN_VE: D1.C, R9.1, U5.5, VE.2
3.3V_EN_VE1: D7.C, R22.1, U7.5, VE1.2
3.3V_EN_VE2: D14.C, R40.1, U12.5, VE2.2
3.3V_EN_VE3: D20.C, R58.1, U17.5, VE3.2
3.3V_QWIIC: C1.1, J2.2, J4.2, R17.2, U4.5
3.3V_QWIIC1: C17.1, J11.2, J14.2, R34.2, U10.5
3.3V_QWIIC2: C26.1, J25.2, J26.2, R52.2, U15.5
3.3V_QWIIC3: C35.1, J37.2, J38.2, R70.2, U20.5
3V3_MEAS: 3V3_MEAS.1, 3V3_MEAS.3, C9.1, C11.1, U5.1
3V3_MEAS1: 3V3_MEAS1.1, 3V3_MEAS1.3, C13.1, C14.1, U7.1
3V3_MEAS2: 3V3_MEAS2.1, 3V3_MEAS2.3, C22.1, C23.1, U12.1
3V3_MEAS3: 3V3_MEAS3.1, 3V3_MEAS3.3, C31.1, C32.1, U17.1
!BOOT!: J1.11, J6.66, S2.3, S2.4
!BOOT!1: J15.11, J21.66, S4.3, S4.4
!BOOT!2: J27.11, J33.66, S6.3, S6.4
!BOOT!3: J39.11, J45.66, S8.3, S8.4
!CS0!-PROCESSOR: J1.55, J6.49
!CS0!-PROCESSOR1: J15.55, J21.49
!CS0!-PROCESSOR2: J27.55, J33.49
!CS0!-PROCESSOR3: J39.55, J45.49
!DFU-FC0!: J6.10, R13.2, U1.P12
!DFU-FC0!1: J21.10, R30.2, U8.P12
!DFU-FC0!2: J33.10, R48.2, U13.P12
!DFU-FC0!3: J45.10, R66.2, U18.P12
!RESET!: J1.6, J5.10, J6.68, J13.1, S1.3, S1.4
!RESET!1: J15.6, J18.10, J19.1, J21.68, S3.3, S3.4
!RESET!2: J27.6, J30.10, J31.1, J33.68, S5.3, S5.4
!RESET!3: J39.6, J42.10, J43.1, J45.68, S7.3, S7.4
!SEL!/2IN: J7.3, R12.1, U1.P10
!SEL!/2IN1: J24.3, R29.1, U8.P10
!SEL!/2IN2: J36.3, R47.1, U13.P10
!SEL!/2IN3: J48.3, R65.1, U18.P10
A0-PROCESSOR: J1.34, J6.38
A0-PROCESSOR1: J15.34, J21.38
A0-PROCESSOR2: J27.34, J33.38
A0-PROCESSOR3: J39.34, J45.38
CTS1-PROCESSOR: J1.15, J6.16
CTS1-PROCESSOR1: J15.15, J21.16
CTS1-PROCESSOR2: J27.15, J33.16
CTS1-PROCESSOR3: J39.15, J45.16
D0-PROCESSOR: J1.10, J6.47
D0-PROCESSOR1: J15.10, J21.47
D0-PROCESSOR2: J27.10, J33.47
D0-PROCESSOR3: J39.10, J45.47
D1-PROCESSOR/SD_CARD_!CS!: J1.18, J10.2
D1-PROCESSOR/SD_CARD_!CS!1: J15.18, J20.2
D1-PROCESSOR/SD_CARD_!CS!2: J27.18, J32.2
D1-PROCESSOR/SD_CARD_!CS!3: J39.18, J44.2
D+: J1.3, J3.A6, J3.B6, U3.6
D+1: J15.3, J17.A6, J17.B6, U9.6
D+2: J27.3, J29.A6, J29.B6, U14.6
D+3: J39.3, J41.A6, J41.B6, U19.6
D-: J1.5, J3.A7, J3.B7, U3.4
D-1: J15.5, J17.A7, J17.B7, U9.4
D-2: J27.5, J29.A7, J29.B7, U14.4
D-3: J39.5, J41.A7, J41.B7, U19.4
G0-PROCESSOR: J1.40, J6.53
G0-PROCESSOR1: J15.40, J21.53
G0-PROCESSOR2: J27.40, J33.53
G0-PROCESSOR3: J39.40, J45.53
G1-PROCESSOR: J1.42, J6.55
G1-PROCESSOR1: J15.42, J21.55
G1-PROCESSOR2: J27.42, J33.55
G1-PROCESSOR3: J39.42, J45.55
G2-PROCESSOR: J1.44, J6.57
G2-PROCESSOR1: J15.44, J21.57
G2-PROCESSOR2: J27.44, J33.57
G2-PROCESSOR3: J39.44, J45.57
G3-PROCESSOR: J1.46, J6.59
G3-PROCESSOR1: J15.46, J21.59
G3-PROCESSOR2: J27.46, J33.59
G3-PROCESSOR3: J39.46, J45.59
G4-PROCESSOR: J1.48, J6.61
G4-PROCESSOR1: J15.48, J21.61
G4-PROCESSOR2: J27.48, J33.61
G4-PROCESSOR3: J39.48, J45.61
GND: 3V3_LED.1, 5V_LED.1, C1.2, C2.2, C3.2, C4.2, C5.2, C8.2, C9.2, C11.2, C12.2, D1.A, DIVIDER.1, H2.1, H4.1, H8.1, J1.1, J1.7, J1.33, J1.36, J1.39, J1.45, J1.75, J2.1, J3.GND, J3.GND2, J4.1, J5.3, J5.5, J5.9, J6.1, J6.2, J6.8, J6.32, J6.33, J6.34, J6.36, J6.39, J6.45, J6.75, J7.4, J8.1, J9.1, J10.6, J10.10, J10.11, J10.12, J10.13, J12.1, QWIIC_LED.1, R1.1, R2.1, R3.1, R6.1, R19.2, S1.1, S1.2, S2.1, S2.2, SHLD.1, U1.P5, U2.2, U3.2, U4.2, U5.4, U5.EP
GND1: 3V3_LED1.1, 5V_LED1.1, C6.2, C7.2, C10.2, C13.2, C14.2, C15.2, C16.2, C17.2, C18.2, D7.A, DIVIDER1.1, H3.1, H10.1, H11.1, J11.1, J14.1, J15.1, J15.7, J15.33, J15.36, J15.39, J15.45, J15.75, J16.1, J17.GND, J17.GND2, J18.3, J18.5, J18.9, J20.6, J20.10, J20.11, J20.12, J20.13, J21.1, J21.2, J21.8, J21.32, J21.33, J21.34, J21.36, J21.39, J21.45, J21.75, J22.1, J23.1, J24.4, QWIIC_LED1.1, R20.1, R21.1, R27.1, R28.1, R36.2, S3.1, S3.2, S4.1, S4.2, SHLD1.1, U6.2, U7.4, U7.EP, U8.P5, U9.2, U10.2
GND2: 3V3_LED2.1, 5V_LED2.1, C19.2, C20.2, C21.2, C22.2, C23.2, C24.2, C25.2, C26.2, C27.2, D14.A, DIVIDER2.1, H13.1, H22.1, H23.1, J25.1, J26.1, J27.1, J27.7, J27.33, J27.36, J27.39, J27.45, J27.75, J28.1, J29.GND, J29.GND2, J30.3, J30.5, J30.9, J32.6, J32.10, J32.11, J32.12, J32.13, J33.1, J33.2, J33.8, J33.32, J33.33, J33.34, J33.36, J33.39, J33.45, J33.75, J34.1, J35.1, J36.4, QWIIC_LED2.1, R38.1, R39.1, R45.1, R46.1, R54.2, S5.1, S5.2, S6.1, S6.2, SHLD2.1, U11.2, U12.4, U12.EP, U13.P5, U14.2, U15.2
GND3: 3V3_LED3.1, 5V_LED3.1, C28.2, C29.2, C30.2, C31.2, C32.2, C33.2, C34.2, C35.2, C36.2, D20.A, DIVIDER3.1, H25.1, H30.1, H31.1, J37.1, J38.1, J39.1, J39.7, J39.33, J39.36, J39.39, J39.45, J39.75, J40.1, J41.GND, J41.GND2, J42.3, J42.5, J42.9, J44.6, J44.10, J44.11, J44.12, J44.13, J45.1, J45.2, J45.8, J45.32, J45.33, J45.34, J45.36, J45.39, J45.45, J45.75, J46.1, J47.1, J48.4, QWIIC_LED3.1, R56.1, R57.1, R63.1, R64.1, R72.2, S7.1, S7.2, S8.1, S8.2, SHLD3.1, U16.2, U17.4, U17.EP, U18.P5, U19.2, U20.2
HOST_D+: J1.35, J6.35
HOST_D+1: J15.35, J21.35
HOST_D+2: J27.35, J33.35
HOST_D+3: J39.35, J45.35
HOST_D-: J1.37, J6.37
HOST_D-1: J15.37, J21.37
HOST_D-2: J27.37, J33.37
HOST_D-3: J39.37, J45.37
I2C_!INT!: J1.16, J6.23
I2C_!INT!1: J15.16, J21.23
I2C_!INT!2: J27.16, J33.23
I2C_!INT!3: J39.16, J45.23
I2C_SCL: J1.14, J2.4, J4.4, J6.21, R15.1
I2C_SCL1: J11.4, J14.4, J15.14, J21.21, R32.1
I2C_SCL1-PROCESSOR/QWIIC_EN: J1.53, R4.1, U4.3
I2C_SCL1-PROCESSOR/QWIIC_EN1: J15.53, R33.1, U10.3
I2C_SCL1-PROCESSOR/QWIIC_EN2: J27.53, R51.1, U15.3
I2C_SCL1-PROCESSOR/QWIIC_EN3: J39.53, R69.1, U20.3
I2C_SCL2: J25.4, J26.4, J27.14, J33.21, R50.1
I2C_SCL3: J37.4, J38.4, J39.14, J45.21, R68.1
I2C_SDA: J1.12, J2.3, J4.3, J6.19, R14.1
I2C_SDA1: J11.3, J14.3, J15.12, J21.19, R31.1
I2C_SDA1-PROCESSOR/!SD_ENABLE!: J1.51, R18.1
I2C_SDA1-PROCESSOR/!SD_ENABLE!1: J15.51, R35.1
I2C_SDA1-PROCESSOR/!SD_ENABLE!2: J27.51, R53.1
I2C_SDA1-PROCESSOR/!SD_ENABLE!3: J39.51, R71.1
I2C_SDA2: J25.3, J26.3, J27.12, J33.19, R49.1
I2C_SDA3: J37.3, J38.3, J39.12, J45.19, R67.1
unnamed: J17.B5, R21.2
unnamed: 5V_LED.2, D8.C
unnamed: D3.A, R11.1
unnamed: J3.B5, R2.2
unnamed: J3.A5, R1.2
unnamed: R3.2, U2.5
unnamed: DIVIDER.2, R7.1
unnamed: D4.C, U2.1
unnamed: D4.A, R5.2
unnamed: 3V3_LED.2, D3.C
unnamed: I2C_PU.3, R14.2
unnamed: D8.A, R8.1
unnamed: I2C_PU.1, R15.2
unnamed: D2.A, R17.1
unnamed: D2.C, QWIIC_LED.2
unnamed: C12.1, J10.4, Q2.3
unnamed: J17.A5, R20.2
unnamed: Q2.1, R18.2, R19.1
unnamed: D9.A, R23.1
unnamed: D11.A, R26.1
unnamed: 5V_LED1.2, D11.C
unnamed: 3V3_LED1.2, D9.C
unnamed: I2C_PU1.3, R31.2
unnamed: I2C_PU1.1, R32.2
unnamed: R27.2, U6.5
unnamed: DIVIDER1.2, R24.1
unnamed: D6.C, U6.1
unnamed: D6.A, R16.2
unnamed: D12.A, R34.1
unnamed: D12.C, QWIIC_LED1.2
unnamed: Q4.1, R35.2, R36.1
unnamed: C16.1, J20.4, Q4.3
unnamed: J29.B5, R39.2
unnamed: J29.A5, R38.2
unnamed: D15.A, R41.1
unnamed: D17.A, R44.1
unnamed: 5V_LED2.2, D17.C
unnamed: 3V3_LED2.2, D15.C
unnamed: I2C_PU2.3, R49.2
unnamed: I2C_PU2.1, R50.2
unnamed: R45.2, U11.5
unnamed: DIVIDER2.2, R42.1
unnamed: D13.C, U11.1
unnamed: D13.A, R37.2
unnamed: D18.A, R52.1
unnamed: D18.C, QWIIC_LED2.2
unnamed: Q6.1, R53.2, R54.1
unnamed: C25.1, J32.4, Q6.3
unnamed: J41.B5, R57.2
unnamed: J41.A5, R56.2
unnamed: D21.A, R59.1
unnamed: D23.A, R62.1
unnamed: 5V_LED3.2, D23.C
unnamed: 3V3_LED3.2, D21.C
unnamed: I2C_PU3.3, R67.2
unnamed: I2C_PU3.1, R68.2
unnamed: R63.2, U16.5
unnamed: DIVIDER3.2, R60.1
unnamed: D19.C, U16.1
unnamed: D19.A, R55.2
unnamed: D24.A, R70.1
unnamed: D24.C, QWIIC_LED3.2
unnamed: Q8.1, R71.2, R72.1
unnamed: C34.1, J44.4, Q8.3
PROCESSOR_CAN-RX: J1.41, J6.43
PROCESSOR_CAN-RX1: J15.41, J21.43
PROCESSOR_CAN-RX2: J27.41, J33.43
PROCESSOR_CAN-RX3: J39.41, J45.43
PROCESSOR_CAN-TX: J1.43, J6.41
PROCESSOR_CAN-TX1: J15.43, J21.41
PROCESSOR_CAN-TX2: J27.43, J33.41
PROCESSOR_CAN-TX3: J39.43, J45.41
PWM0-PROCESSOR: J1.32, J6.51
PWM0-PROCESSOR1: J15.32, J21.51
PWM0-PROCESSOR2: J27.32, J33.51
PWM0-PROCESSOR3: J39.32, J45.51
PWR_EN0: J1.47, J6.71
PWR_EN1: J15.47, J21.71
PWR_EN2: J27.47, J33.71
PWR_EN3: J39.47, J45.71
RTS1-PROCESSOR: J1.13, J6.18
RTS1-PROCESSOR1: J15.13, J21.18
RTS1-PROCESSOR2: J27.13, J33.18
RTS1-PROCESSOR3: J39.13, J45.18
RX1-DFU_TX-FC0-PLEX: J6.4, U1.P9
RX1-DFU_TX-FC0-PLEX1: J21.4, U8.P9
RX1-DFU_TX-FC0-PLEX2: J33.4, U13.P9
RX1-DFU_TX-FC0-PLEX3: J45.4, U18.P9
RX1-PROCESSOR: J1.19, U1.P6
RX1-PROCESSOR1: J15.19, U8.P6
RX1-PROCESSOR2: J27.19, U13.P6
RX1-PROCESSOR3: J39.19, U18.P6
RX1-PROCESSOR-PLEX: J6.13, U1.P7
RX1-PROCESSOR-PLEX1: J21.13, U8.P7
RX1-PROCESSOR-PLEX2: J33.13, U13.P7
RX1-PROCESSOR-PLEX3: J45.13, U18.P7
RX1/2S1: J24.2, U8.P8
RX1/2S2: J7.2, U1.P8
RX1/2S3: J36.2, U13.P8
RX1/2S4: J48.2, U18.P8
SHLD: J3.SHLD1, J3.SHLD2, J3.SHLD3, J3.SHLD4, SHLD.2
SHLD1: J17.SHLD1, J17.SHLD2, J17.SHLD3, J17.SHLD4, SHLD1.2
SHLD2: J29.SHLD1, J29.SHLD2, J29.SHLD3, J29.SHLD4, SHLD2.2
SHLD3: J41.SHLD1, J41.SHLD2, J41.SHLD3, J41.SHLD4, SHLD3.2
SPI_PROCESSOR_SCK: J1.57, J6.3, J10.5
SPI_PROCESSOR_SCK1: J15.57, J20.5, J21.3
SPI_PROCESSOR_SCK2: J27.57, J32.5, J33.3
SPI_PROCESSOR_SCK3: J39.57, J44.5, J45.3
SPI_PROCESSOR_SDI: J1.61, J6.7, J10.7
SPI_PROCESSOR_SDI1: J15.61, J20.7, J21.7
SPI_PROCESSOR_SDI2: J27.61, J32.7, J33.7
SPI_PROCESSOR_SDI3: J39.61, J44.7, J45.7
SPI_PROCESSOR_SDO: J1.59, J6.5, J10.3
SPI_PROCESSOR_SDO1: J15.59, J20.3, J21.5
SPI_PROCESSOR_SDO2: J27.59, J32.3, J33.5
SPI_PROCESSOR_SDO3: J39.59, J44.3, J45.5
SWDCK: J1.21, J5.4
SWDCK1: J15.21, J18.4
SWDCK2: J27.21, J30.4
SWDCK3: J39.21, J42.4
SWDIO: J1.23, J5.2, TP1.1
SWDIO1: J15.23, J18.2, TP8.1
SWDIO2: J27.23, J30.2, TP12.1
SWDIO3: J39.23, J42.2, TP16.1
TX1-DFU_RX-FC0-PLEX: J6.6, U1.P1
TX1-DFU_RX-FC0-PLEX1: J21.6, U8.P1
TX1-DFU_RX-FC0-PLEX2: J33.6, U13.P1
TX1-DFU_RX-FC0-PLEX3: J45.6, U18.P1
TX1-PROCESSOR: J1.17, U1.P4
TX1-PROCESSOR1: J15.17, U8.P4
TX1-PROCESSOR2: J27.17, U13.P4
TX1-PROCESSOR3: J39.17, U18.P4
TX1-PROCESSOR-PLEX: J6.15, U1.P3
TX1-PROCESSOR-PLEX1: J21.15, U8.P3
TX1-PROCESSOR-PLEX2: J33.15, U13.P3
TX1-PROCESSOR-PLEX3: J45.15, U18.P3
TX1/1S1: J24.1, U8.P2
TX1/1S2: J7.1, U1.P2
TX1/1S3: J36.1, U13.P2
TX1/1S4: J48.1, U18.P2
VCC: 5V_MEAS.1, 5V_MEAS.3, C2.1, D5.C, J6.72, J6.74, Q1.2, R4.2, U4.1
VCC1: 5V_MEAS1.1, 5V_MEAS1.3, C18.1, D10.C, J21.72, J21.74, Q3.2, R33.2, U10.1
VCC2: 5V_MEAS2.1, 5V_MEAS2.3, C27.1, D16.C, J33.72, J33.74, Q5.2, R51.2, U15.1
VCC3: 5V_MEAS3.1, 5V_MEAS3.3, C36.1, D22.C, J45.72, J45.74, Q7.2, R69.2, U20.1
VCC_MEAS: 5V_MEAS.2, 5V_MEAS.4, C5.1, C8.1, R9.2, U5.8
VCC_MEAS1: 5V_MEAS1.2, 5V_MEAS1.4, C10.1, C15.1, R22.2, U7.8
VCC_MEAS2: 5V_MEAS2.2, 5V_MEAS2.4, C21.1, C24.1, R40.2, U12.8
VCC_MEAS3: 5V_MEAS3.2, 5V_MEAS3.4, C30.1, C33.1, R58.2, U17.8
VIN: BYP.2, C3.1, D5.A, F2.2, J1.9, Q1.1, R5.1, R6.2, R8.2, R10.2, TP4.1, U2.4
VIN1: BYP1.2, C6.1, D10.A, F1.2, J15.9, Q3.1, R16.1, R25.2, R26.2, R28.2, TP7.1, U6.4
VIN2: BYP2.2, C19.1, D16.A, F3.2, J27.9, Q5.1, R37.1, R43.2, R44.2, R46.2, TP11.1, U11.4
VIN3: BYP3.2, C28.1, D22.A, F4.2, J39.9, Q7.1, R55.1, R61.2, R62.2, R64.2, TP15.1, U16.4
VIN/1: J15.49, R24.2, R25.1
VIN/2: J27.49, R42.2, R43.1
VIN/3: J1.49, R7.2, R10.1
VIN/4: J39.49, R60.2, R61.1
V_BATT: C4.1, J8.2, J12.2, Q1.3, TP3.1, U2.3
V_BATT1: C7.1, J16.2, J23.2, Q3.3, TP6.1, U6.3
V_BATT2: C20.1, J28.2, J35.2, Q5.3, TP10.1, U11.3
V_BATT3: C29.1, J40.2, J47.2, Q7.3, TP14.1, U16.3
V_USB: BYP.1, F2.1, J3.VBUS1, J3.VBUS2, U3.5
V_USB1: BYP1.1, F1.1, J17.VBUS1, J17.VBUS2, U9.5
V_USB2: BYP2.1, F3.1, J29.VBUS1, J29.VBUS2, U14.5
V_USB3: BYP3.1, F4.1, J41.VBUS1, J41.VBUS2, U19.5

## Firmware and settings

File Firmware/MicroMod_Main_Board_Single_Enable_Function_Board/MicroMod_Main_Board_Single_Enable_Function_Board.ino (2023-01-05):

/******************************************************************************

  WRITTEN BY: Ho Yun "Bobby" Chan
  @ SparkFun Electronics
  UPDATED: 1/3/2023
  DATE: 10/19/2021
  GITHUB REPO: https://github.com/sparkfun/SparkFun_MicroMod_Main_Board_Single
  DEVELOPMENT ENVIRONMENT SPECIFICS:
    Firmware developed using Arduino IDE v1.8.12

  ========== DESCRIPTION==========
  This example code toggles the Function Board's AP2112 3.3V voltage 
  regulator's enable pin. The Function Boards built-in power LED should blink.
  This example is based on Arduino's built-in Blink Example:

      https://www.arduino.cc/en/Tutorial/BuiltInExamples/Blink

  Note that this example code uses the MicroMod Main Board - Single. The MicroMod
  Main Board - Double routes the PWR_EN# pins slightly different for the
  two function boards. 

  ========== HARDWARE CONNECTIONS ==========
  MicroMod Artemis Processor Board => MicroMod Main Board - Single => Function Board

  Feel like supporting open source hardware?
  Buy a board from SparkFun!
       MicroMod Artemis Processor Board - https://www.sparkfun.com/products/16401
       MicroMod Main Board - Single - https://www.sparkfun.com/products/20748
       MicroMod Environmental Function Board - https://www.sparkfun.com/products/18632

  LICENSE: This code is released under the MIT License (http://opensource.org/licenses/MIT)

******************************************************************************/

/*Define the power enable pins for the processor board with either SDIO_DATA2 or A1.
  Depending on the processor board, the Arduino pin may be different. 

  Note: For MicroMod Main Board - Single v2.1, there is now only one GPIO available 
        to toggle the Power Enable 0 (PWR_EN0) pin. The previous defines for a few 
        Processor Boards are still available for those that have v1.1.

        For MicroMod Main Board - Single v1.1, certain Processor Boards like the 
        Artemis have SDIO_DATA2 and A1 available to control the Function Board's
        voltage regulator. SAMD51, ESP32, and STM32 Processor Board pins do not 
        have SDIO_DATA2, so users will need to reference the Processor Pin A1.
        Below are a few examples.*/



//==========ARTEMIS==========
//Function Board 0's "PWR_EN0" pin <= MicroMod Main - Single v2.1 PWM1 => Artemis Processor Board (D45)
#define PWR_EN0 45

//Function Board 0's "PWR_EN0" pin <= MicroMod Main - Single v1.1 SDIO_DATA2 => Artemis Processor Board (D4)
//#define PWR_EN0 4

//Alternative option that does the same thing. Make sure to just choose one for PWR_EN0
//Function Board 0's "PWR_EN0" pin <= MicroMod Main - Single v1.1 A1 => Artemis Processor Board (A35)
//#define PWR_EN0 35



//==========TEENSY==========
//Function Board 0's "PWR_EN0" pin <= MicroMod Main- Single v2.1 PWM1 => Teensy Processor Board (2)
//#define PWR_EN0 2

//Function Board 0's "PWR_EN0" pin <= MicroMod Main - Single v1.1 SDIO_DATA2 => Teensy Processor Board (39)
//#define PWR_EN0 39

//Alternative option that does the same thing. Make sure to just choose one for PWR_EN0
//Function Board 0's "PWR_EN0" pin <= MicroMod Main - Single v1.1 A1 => Teensy Processor Board (A1)
//#define PWR_EN0 15



//Note: For those using Main - Single v1.1;
//      SAMD51, ESP32, and STM32 Processor Board Pins
//      do not have SDIO_DATA2 and SDIO_DATA1.

//==========SAMD51==========
//Function Board 0's "PWR_EN0" pin <= MicroMod Main - Single v2.1 PWM1 => SAMD51 Processor Board (20)
//#define PWR_EN0 20

//Function Board 0's "PWR_EN0" pin <= MicroMod Main - Single v1.1 A1 => SAMD51 Processor Board (18)
//#define PWR_EN0 18


//==========ESP32==========
//Function Board 0's "PWR_EN0" pin <= MicroMod Main - Single v2.1 PWM1 => ESP32 Processor Board (12)
//#define PWR_EN0 12

//Function Board 0's "PWR_EN0" pin <= MicroMod Main - Single v1.1 A1 => ESP32 Processor Board (35)
//#define PWR_EN0 35



void setup() {
  // initialize the digital pin as an output.
    pinMode(PWR_EN0, OUTPUT);
}



void loop() {
  digitalWrite(PWR_EN0, HIGH); // turn the 3.3V regulator on (HIGH is the voltage level)
  delay(5000);                 // wait for a few seconds to do something with the function boards

  digitalWrite(PWR_EN0, LOW);  // turn the 3.3V regulator off by making the voltage LOW
  delay(5000);                 // wait for a few seconds before turning function boards back on

}

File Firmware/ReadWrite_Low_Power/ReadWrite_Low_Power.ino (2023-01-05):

/*
  SD Card Read/Write

  This example shows how to read and write data to and from an SD card file
  The circuit:

  SD card attached to SPI bus as follows:

   SD Card   <=> MicroMod Main Board <=> Artemis Processor Board
   -----------------------------------------------------------------
   SD ENABLE <=>  I2C_SDA1-PROCESSOR <=> pin 9
   PICO/SDO  <=>  SPI_PROCESSOR_SDO  <=> pin 38
   POCI/SDI  <=>  SPI_PROCESSOR_SDI  <=> pin 43
   CLK       <=>  SPI_PROCESSOR_SCK  <=> pin 42
   CS        <=>  D1_PROCESSOR       <=> pin 1 (Main Board - Single)
   or ...
   CS        <=>  G4_PROCESSOR       <=> pin 28 (Main Board - Double)

  created   Nov 2010
  by David A. Mellis
  modified 9 Apr 2012
  by Tom Igoe

  This example code is in the public domain.

*/

#include <SPI.h>
#include <SD.h>

//==========ARTEMIS==========
// The microSD Card CS pin is D1 for the MicroMod Main Board - Single and Artemis Processor (D1). Adjust for your processor if necessary.
const int SD_CS_PIN = 1;
// The microSD Card's CS pin is G4 for the MicroMod Main Board - Double and Artemis Processor (D28). Adjust for your processor if necessary.
//const int SD_CS_PIN = 28; 

// The microSD Card CS pin is SDA1 for the MicroMod Main Board - Single and Artemis Processor (D9). Adjust for your processor if necessary.
const int SD_ENABLE = 9;

File myFile;

void setup() {

  pinMode(SD_ENABLE, OUTPUT);  //sets the digital pin as output
  digitalWrite(SD_ENABLE, LOW);  //Power MicroSD card socket, pin is active low

  // Open serial communications and wait for port to open:
  Serial.begin(9600);
  while (!Serial) {
    ; // wait for serial port to connect. Needed for native USB port only
  }


  Serial.print("Initializing SD card...");

  if (!SD.begin(SD_CS_PIN)) {
    Serial.println("initialization failed!");
    while (1);
  }
  Serial.println("initialization done.");

  // open the file. note that only one file can be open at a time,
  // so you have to close this one before opening another.
  myFile = SD.open("test.txt", FILE_WRITE);

  // if the file opened okay, write to it:
  if (myFile) {
    Serial.print("Writing to test.txt...");
    myFile.println("testing 1, 2, 3.");
    // close the file:
    myFile.close();
    Serial.println("done.");
  } else {
    // if the file didn't open, print an error:
    Serial.println("error opening test.txt");
  }

  // re-open the file for reading:
  myFile = SD.open("test.txt");
  if (myFile) {
    Serial.println("test.txt:");

    // read from the file until there's nothing else in it:
    while (myFile.available()) {
      Serial.write(myFile.read());
    }
    // close the file:
    myFile.close();
  } else {
    // if the file didn't open, print an error:
    Serial.println("error opening test.txt");
  }

  digitalWrite(SD_ENABLE, HIGH);  //remove power from MicroSD card socket for low power applications

}// end setup()

void loop() {
  // nothing happens after setup

}//end loop()

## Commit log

2021-08-17 Initial commit (post-prototype, pre finalized for REDs)
    [Motherboard_Single.GBL, Motherboard_Single.GBO, Motherboard_Single.GBP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]
2021-08-17 Rename "Single Function Board" folder to "Hardware"
    [Motherboard_Single.brd, Motherboard_Single.sch]
2021-08-31 Adds another standoff for qwiic boards around the lower left edge, adds silk
    * Removes jumper for "VIN/VUSB"
    * Correctly routes USB_VIN on processor connector to VIN
    * Double routes PWR_EN for ESP32 Processor boards
    * Moves SD Card up 0.04"
    * Adds more measures
    [Motherboard_Single.brd, Motherboard_Single.sch]
2021-09-02 Adds 2 pin dip switch for charge selection, adds PCHAN MOSFET to VBATT net
    * Adds better silk
    * Moves stuff around schematic for better clarity
    * Adds charge table to schematic
    [Motherboard_Single.brd, Motherboard_Single.sch]
2021-09-02 Replaces MOSFET with another one
    [Motherboard_Single.brd, Motherboard_Single.sch]
2021-09-03 Adds 10k pulldown to gate on PCHAN MOSFET, fixes length measurement
    [Motherboard_Single.brd, Motherboard_Single.sch]
2021-09-07 Adds prod_id to function board connector, double routes power enable to A1 and previous pin
    [Motherboard_Single.brd, Motherboard_Single.sch]
2021-09-10 Moves SD Card slightly towards center of PCB
    [Motherboard_Single.brd]
2021-09-10 Changes eagle file names
    [Main Board - Single-Panel.GBL, Main Board - Single-Panel.GBO, Main Board - Single-Panel.GBP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]
2021-09-10 Adds new panel
    [Main Board - Single-Panel.GBL, Main Board - Single-Panel.GBO, Main Board - Single-Panel.GBP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]
2021-09-10 Adds a larger manufacturing panel than the previous
    [Main Board - Single-Panel.GBL, Main Board - Single-Panel.GBO, Main Board - Single-Panel.GBS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]
2021-09-10 Adds new panel that is two columns of three
    [Main Board - Single-Panel.GBL, Main Board - Single-Panel.GBO, Main Board - Single-Panel.GBS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]
2021-10-11 Changes power to Function boards @ VCC to VCC and not VIN
    [Main Board - Single.brd, Main Board - Single.sch]
2021-10-11 Rolls to V11
    [Main Board - Single.brd, Main Board - Single.sch]
2021-10-22 Replaces shottky diode
    [Main Board - Single.brd, Main Board - Single.sch]
2021-11-03 Updates function board symbol, fixes charging current value when 1 and 2 are flipped.
    [Main Board - Single.brd, Main Board - Single.sch]
2021-11-08 remove MicroMod Main Board - Double reference
2021-11-10 Create ReadWrite.ino
    Included modified example with a microSD card from the SD Arduino Library
2021-11-11 Updates the design to use the Micromod-function device in the official SFE Eagle Libs
    [Main Board - Single.brd, Main Board - Single.sch]
2022-07-21 Adds initial commit to Main Board Single v20
    [Main Board - Single v20.brd, Main Board - Single v20.sch]
2022-07-21 Adds new board files?
2022-08-18 Adds completely updated design - update in Fusion360, imported back to Eagle 9 for silk
    [Main Board - Single v20_v4.brd, Main Board - Single v20_v4.sch]
2022-08-18 Removes old versions
    [Main Board - Single v20.brd, Main Board - Single v20.sch, Main Board - Single.brd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]
2022-08-18 Rolls version to v20
    [Main Board - Single v20_v4.brd, Main Board - Single v20_v4.sch]
2022-08-19 * Adds 4-pin header for other DFU lines
    * Updates silk
    * Uses VIN as power supply to battery charger
    * Fixes PCH Mosfet
    * Fixes polygons where applicable
    * Adds SparkFun logo to topside.
    [Main Board - Single v20_v4.brd, Main Board - Single v20_v4.sch]
2022-08-19 Adds qwiic LED silk
    [Main Board - Single v20_v4.brd]
2022-08-19 Fixes airwire
    [Main Board - Single v20_v4.brd]
2022-08-23 Renames board files
    [SparkFun_Main_Board_Single_v20.brd, SparkFun_Main_Board_Single_v20.sch]
2022-08-23 Fixes measure pth alignment
    [SparkFun_Main_Board_Single_v20.brd]
2022-08-23 Adds new production files
    [Main Board - Single-Panel.GBL, Main Board - Single-Panel.GBO, Main Board - Single-Panel.GBS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]
2022-08-23 Remakes production files
    [SparkFun_Main_Board_Single_v20-Panel.brd, SparkFun_Main_Board_Single_v20.brd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]
2022-08-24 Updates silk on multiplexing PTH
    [SparkFun_Main_Board_Single_v20.brd, SparkFun_Main_Board_Single_v20.sch]
2022-08-24 Updates production files
    [SparkFun_Main_Board_Single_v20-Panel.brd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]
2022-08-24 Adds PROD_ID to UART switcher
    [SparkFun_Main_Board_Single_v20.brd, SparkFun_Main_Board_Single_v20.sch]
2022-09-02 Updates PROD ID on VREG
    [SparkFun_Main_Board_Single_v20.brd, SparkFun_Main_Board_Single_v20.sch]
2022-10-26 Routes PWM1 pin to power enable pin on function card
    * Rolls version to v21
    * Fixes PTC silk
    [SparkFun_Main_Board_Single_v20.brd, SparkFun_Main_Board_Single_v20.sch]
2022-10-28 Rotates JST connector, fixes some silk labels
    [SparkFun_Main_Board_Single_v20.brd]
2022-10-28 Moves JST connector in 0.1"
    [SparkFun_Main_Board_Single_v20.brd]
2022-10-28 Adds notch for batteries, moves VBAT test point
    [SparkFun_Main_Board_Single_v20.brd]
2022-10-28 Renames files to match PCB version numver
    [SparkFun_Main_Board_Single_v21.brd, SparkFun_Main_Board_Single_v21.sch]
2022-10-31 Fixes width DRC errors
    [SparkFun_Main_Board_Single_v21.brd]
2023-01-03 Updat input voltage range on the VREG
    [SparkFun_Main_Board_Single_v21.sch]
2023-01-04 Update MicroMod_Main_Board_Single_Enable_Function_Board.ino
    - update comments and notes
    - include updated GPIO pin to toggle PWR_EN0
2023-01-04 Create ReadWrite_Low_Power.ino
    Add example to toggle microSD card Socket's power for low power applications
2023-01-04 Create MicroMod_Main_Enable_Qwiic_Boards.ino
    Add example to toggle Qwiic Port's voltage regulator for low power
2023-05-03 Updates function board symbol
    [SparkFun_Main_Board_Single_v21.brd, SparkFun_Main_Board_Single_v21.sch]

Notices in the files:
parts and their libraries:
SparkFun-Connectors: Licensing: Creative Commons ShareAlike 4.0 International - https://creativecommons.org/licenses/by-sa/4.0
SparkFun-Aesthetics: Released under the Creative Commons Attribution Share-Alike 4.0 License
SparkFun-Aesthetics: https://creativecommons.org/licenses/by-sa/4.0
